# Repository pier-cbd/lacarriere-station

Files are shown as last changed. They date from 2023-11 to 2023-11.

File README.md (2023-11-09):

# Lacarriere Station 

## Specs
### Stage 1
- Powered by a battery recharged by a solar panel
- Three VGA cameras to take 360° photos
- Measures temperature/humidity/pressure with Bosch sensors
- Sends data via 2G+ network
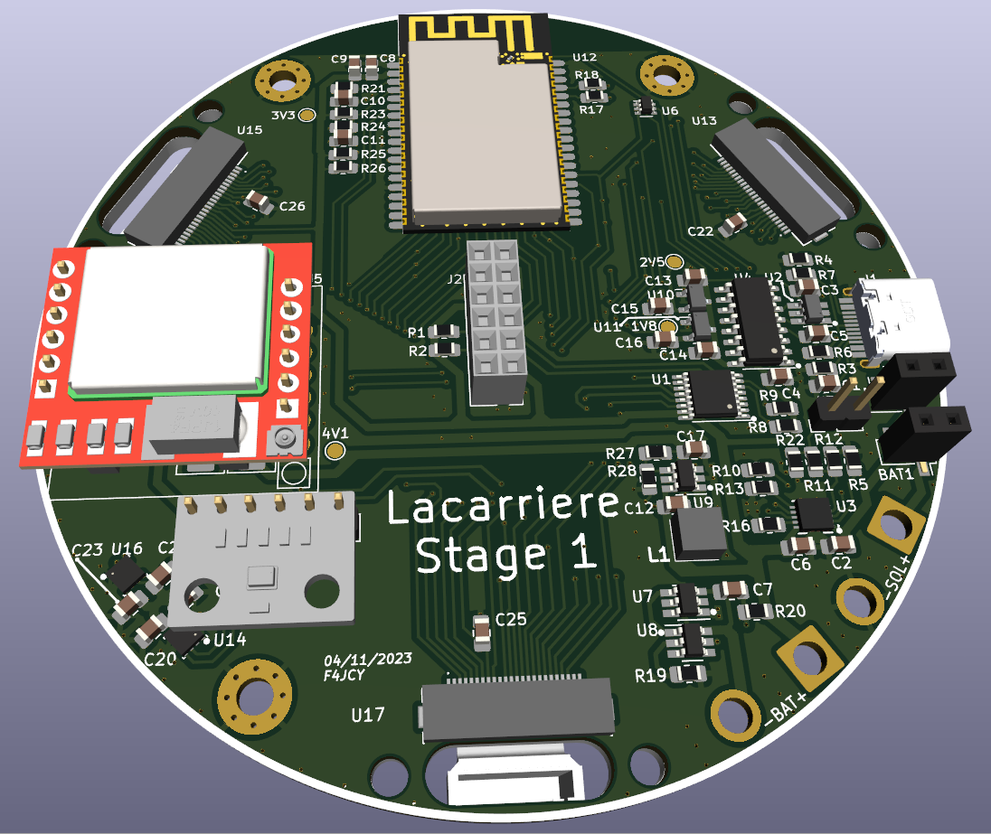
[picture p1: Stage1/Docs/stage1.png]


### Stage 2
...

### Stage 3
...

## Sofwares
- KiCAD 7
- FreeCAD 0.20

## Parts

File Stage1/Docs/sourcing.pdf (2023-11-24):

3 Proto Budget : | 211,968 € | | Mouser Order Aliexpress Order
Price | VAT/Shipping | Already in stock
Mouser Order | 79,88 | 15,98 | Not a component
Aliexpress Order | 16,81 | 6,25
JLCPCB Manufacturing | 2 | 15
Review | 40
Quantity | Designator | Footprint | Designation | STOCK

ORDER
quantity

Mouser
Order

Aliexpress
Order
REF | Price(HT) | Minimum | Manufacturer | REF | Price (€) | Min | Manufacturer | Price (€) | shipping | Minimum
2V8,1V3,3V3,4V1 | TestPoint_Pad_D1.5mmTestPoint
11 | C21,C17,C23,C7,C8,C1,C3,C20,C5,C24,C4 C_0805_2012Metric_Pad1.18x1.45mm_HandSolder 0.1u | 581-KGM21NR71E104KT | 0,093 | 1 | sss | C1711 | 0,0056 | 100 | Samsung Electro-Mechanics | 0 | 35 | 1,05
2 | C18, (C19) | CP_EIA-7343-31_Kemet-D_Pad2.25x2.55mm_HandSolder 100u | 80-T491D107K016 | 0,921 | 1 | KEMET | C110548 | 0,5201 | 1 | KEMET | 0 | 5 | 4,605
3 | C22,C25,C26 | C_0805_2012Metric_Pad1.18x1.45mm_HandSolder 15p | 581-08053A150KAT2A | 0,167 | 1 | KYOCERA AVX | C1794 | 0,0121 | 50 | Samsung Electro-Mechanics | 0 | 15 | 1,91
9 | C2,C16,C13,C10,C12,C15,C14,C6,(C11) C_0805_2012Metric_Pad1.18x1.45mm_HandSolder 1u | 581-KAF21KR71H105KU | 0,288 | 1 | KYOCERA AVX | C28323 | 0,0083 | 50 | Samsung Electro-Mechanics | 44
1 | C9 | C_0805_2012Metric_Pad1.18x1.45mm_HandSolder 10u | 581-0805YC106KAT2A | 0,846 | 1 | KYOCERA AVX | C15850 | 0,0101 | 50 | Samsung Electro-Mechanics | 0 | 10 | 7,47
CON-BAT+ | SolderWire-2.5sqmm_1x02_P8.8mm_D2.4mm_OD4.4mm LiFePo4
CON-SOL+ | SolderWire-2.5sqmm_1x02_P8.8mm_D2.4mm_OD4.4mm Solar_Cell
1 | J1 | USB_C_Receptacle_HRO_TYPE-C-31-M-12 USB_C_USB2.0 | 640-USB4105-GF-A-120 | 0,772 | 1 | GCT | C167321 | 0,3374 | 5 | Jing Extension of the Elec Co. | 0 | 5 | 3,86
1 | J2 | CENTRAL-HEADER Conn_02x06 | 0,398 | 3,52 | 10 | 0 | 20 | 11,48
2 | J4 | PinHeader_1x06_P2.54mm_Vertical (BME KIT) Conn_01x06_Pin | 4,44 | 1 | 2
2 | JUMPER-BAT1, JUMPER-USB1 PinSocket_1x02_P2.54mm_Vertical_SMD_Pin1Right Jumper_2_Bridged | C917636 | 0,0387 | 10 | XKB Connectivity | 15
1 | L1 | XEL4030-222MEC | 2.2u | 994-XEL4030-222MEC | 2,26 | 1 | Coilcraft | C2998753 | 0,6235 | 1 | Sumida | 0 | 3 | 6,78
R11 | R_0805_2012Metric_Pad1.20x1.40mm_HandSolder NC
1 | R13 | R_0805_2012Metric_Pad1.20x1.40mm_HandSolder 62k | 71-CRCW080562K0FKEA | 0,093 | 1 | Vishay / Dale | C17783 | 0,0017 | 100 | UNI-ROYAL(Uniroyal Elec) | 0 | 10 | 0,23
3 | R18,R17,R20 | R_0805_2012Metric_Pad1.20x1.40mm_HandSolder 100R | 71-CRCW0805-100-E3 | 0,093 | 1 | Vishay / Dale | C17408 | 0,0018 | 100 | UNI-ROYAL(Uniroyal Elec) | 0 | 20 | 0,62
1 | R19 | R_0805_2012Metric_Pad1.20x1.40mm_HandSolder 2k | 71-CRCW08052K00JNEA | 0,093 | 1 | Vishay / Dale | C17804 | 0,0018 | 100 | UNI-ROYAL(Uniroyal Elec) | 0 | 10 | 0,19
1 | R5 | R_0805_2012Metric_Pad1.20x1.40mm_HandSolder 375R(0,8A) 750R(0.4A) | 71-CRCW0805-750-E3 | 0,093 | 1 | Vishay / Dale | C17818 | 0,0017 | 100 | UNI-ROYAL(Uniroyal Elec) | 0 | 10 | 0,23
6 | R25,R2,R21,R1,R22,R26 | R_0805_2012Metric_Pad1.20x1.40mm_HandSolder 10k | 71-CRCW080510K0FKEAC | 0,093 | 1 | Vishay / Dale | C17417 | 0,0014 | 100 | UNI-ROYAL(Uniroyal Elec) | 99
1 | R28 | R_0805_2012Metric_Pad1.20x1.40mm_HandSolder 14k | 71-CRCW0805-14K-E3 | 0,093 | 1 | Vishay / Dale | C17467 | 0,0017 | 100 | UNI-ROYAL(Uniroyal Elec) | 0 | 10 | 0,23
2 | R24,R23 | R_0805_2012Metric_Pad1.20x1.40mm_HandSolder 1M | 71-CRCW08051M00FKEAC | 0,093 | 1 | Vishay / Dale | C17514 | 0,0018 | 100 | UNI-ROYAL(Uniroyal Elec) | 98
2 | R3,R4 | R_0805_2012Metric_Pad1.20x1.40mm_HandSolder 5.1k | 71-CRCW08055K10JNEA | 0,093 | 1 | Vishay / Dale | C27834 | 0,0018 | 100 | UNI-ROYAL(Uniroyal Elec) | 0 | 20 | 0,46
4 | R9,R16,R27,R8 | R_0805_2012Metric_Pad1.20x1.40mm_HandSolder 100k | 71-CRCW0805100KFKEBC | 0,093 | 1 | Vishay / Dale | C149504 | 0,0018 | 100 | UNI-ROYAL(Uniroyal Elec) | 0 | 20 | 0,58
6 | R10,R7,R15,R6,R14,R11 | R_0805_2012Metric_Pad1.20x1.40mm_HandSolder 0R | 71-CRCW08050000Z0EC | 0,093 | 1 | Vishay / Dale | C17477 | 0,0016 | 100 | UNI-ROYAL(Uniroyal Elec) | 0 | 20 | 0,46
TH1 | PinHeader_1x02_P2.54mm_Vertical NTC
1 | U1 | TSSOP-16_4.4x5mm_P0.65mm PCA9557PW | 595-PCA9557PWR | 1,4 | 1 | Texas Instruments | C141380 | 0,43 | 1 | NXP Semicon | 0 | 3 | 4,2
1 | U10 | SOT-23-3 | XC6206P182MR-G | 865-XC6206P182MR-G | 0,651 | 1 | Torex Semiconductor | C424700 | 0,1349 | 5 | Torex Semiconductor | 0 | 5 | 3,255
1 | U11 | SOT-23-3 | XC6206P252MR-G | 865-XC6206P252MR-G | 0,577 | 1 | Torex Semiconductor | C5250983 | 0,0168 | 20 | TWGMC | 0
1 | U12 | ESP32-WROVER | ESP32_WROVER | 356-ESP32WRVIE2864UC | 3,15 | 1 | Espressif Systems | C529591 | 3,9246 | 1 | Espressif Systems | 0 | 3 | 9,45
3 | U15,U13,U17 | F34G1A7Q1E8C24 ~ | 649-F34G1A7Q1E8C24 | 0,437 | 1 | Amphenol Aorora | C5373439 | 0,0636 | 5 | SHOU HAN | 0 | 10 | 3,71
2 | U14,U16 | Bosch_LGA-8_2.5x2.5mm_P0.65mm_ClockwisePinNumbering BME280 | 262-BME280 | 5,9 | 1 | Bosch Sensortec | C92489 | 3,4781 | 1 | Bosch Sensortec | 0 | 4 | 23,6
1 | U2 | SOT-23-6_Handsoldering USBLC6-2SC6 | 511-USBLC6-2SC6 | 0,567 | 1 | STMicroelectronics
1 | U3 | VSON10_BQ25171_3X3_TEX-M BQ25171QWDRCRQ1 | 595-BQ25171QWDRCRQ1 | 1,71 | 1 | Texas Instruments | C2861221 | 1,3995 | 1 | Texas Instruments | 12
1 | U4 | SOIC-16_3.9x9.9mm_P1.27mm CH340C | C84681 | 0,4433 | 1 | WCH(Jiangsu Qin Heng) | 0,468 | 0,56 | 10 | 0 | 10 | 5,24
1 | U6 | SOT-363_SC-70-6 | UMH3N | 755-UMH3NTN | 0,428 | 1 | ROHM Semiconductor | C62892 | 0,0502 | 10 | Jiangsu Changjing | 0 | 5 | 2,14
1 | U5 | SIM800L-CORE | SIM800L-CORE | 2,77 | 1 | 2
1 | U7 | SOT-23-6_Handsoldering FS8205 | C32254 | 0,169 | 5 | Fortune Semicon | 0,098 | 0,84 | 10 | 0 | 10 | 1,82
1 | U8 | SOT-23-6_Handsoldering HY2112 (HB) | C168763 | 0,1222 | 5 | HYCON Tech | 0,319 | 1,33 | 10 | 0 | 10 | 4,52
1 | U9 | SOT-23-6_Handsoldering TLV61070A | 595-TLV61070ADBVR | 0,465 | 1 | Texas Instruments | C6881375 | 0,2857 | 5 | Texas Instruments | 0 | 5 | 2,325
77,355 | 23,06
Mouser | LCSC | Aliexpress

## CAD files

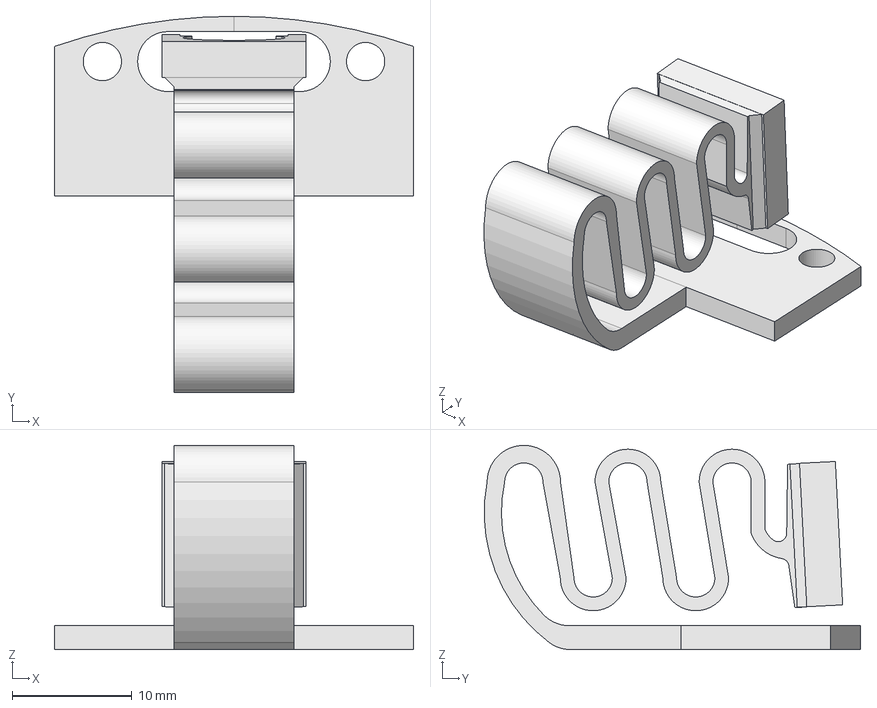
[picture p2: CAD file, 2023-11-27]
Stage1/Kicad/3D/CAMERA_HOLDER_V7.step
30.0 x 31.4 x 17.1 mm

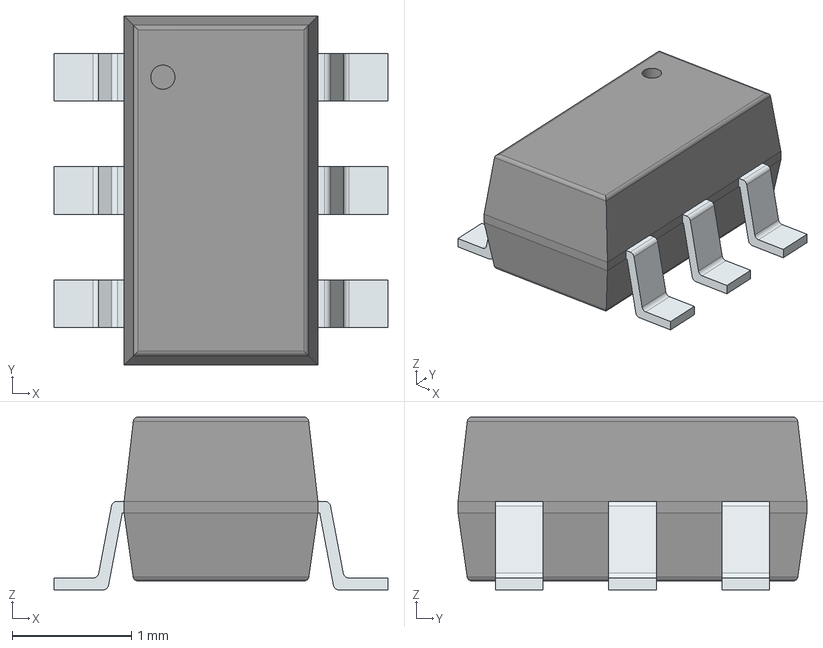
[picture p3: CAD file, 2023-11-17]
Stage1/Kicad/3D/USBLC6-2SC6.stp
2.80 x 2.92 x 1.45 mm
PinsArrayLR

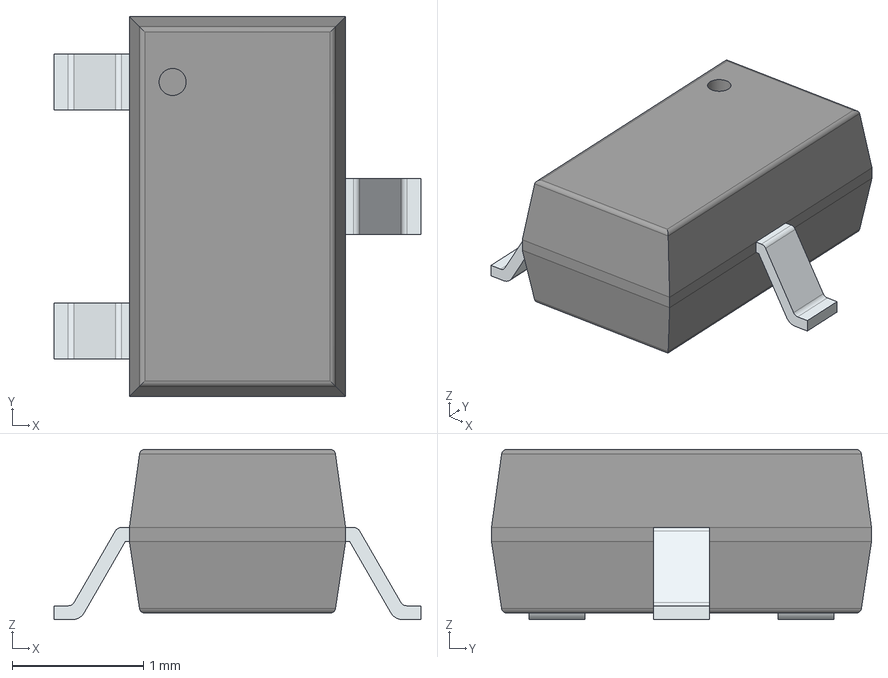
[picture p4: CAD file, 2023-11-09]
Stage1/Kicad/3D/XC6206P282MR-G.stp
2.80 x 2.90 x 1.30 mm
PinsArrayL
FilletPinR

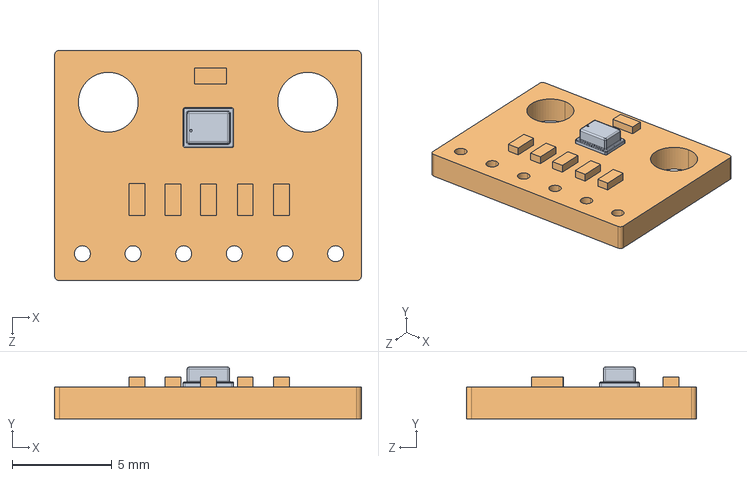
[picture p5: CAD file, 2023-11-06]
Stage1/Kicad/3D/BME280_SENSOR_MODULE.STEP
15.4 x 2.60 x 11.6 mm

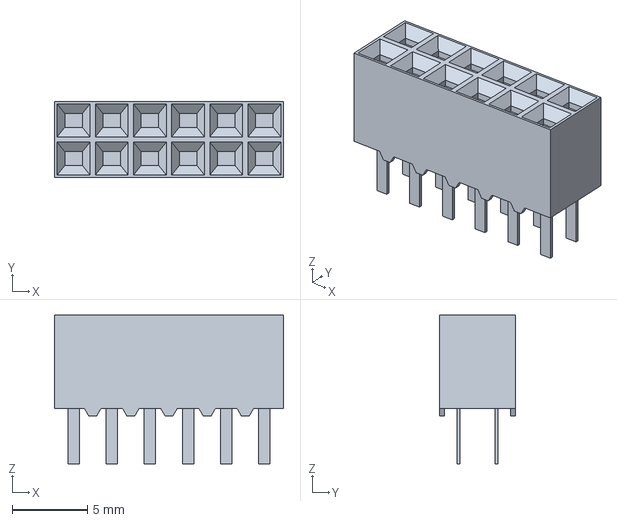
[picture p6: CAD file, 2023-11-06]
Stage1/Kicad/3D/CENTRAL_HEADER_02x06.stp
15.2 x 5.03 x 9.91 mm

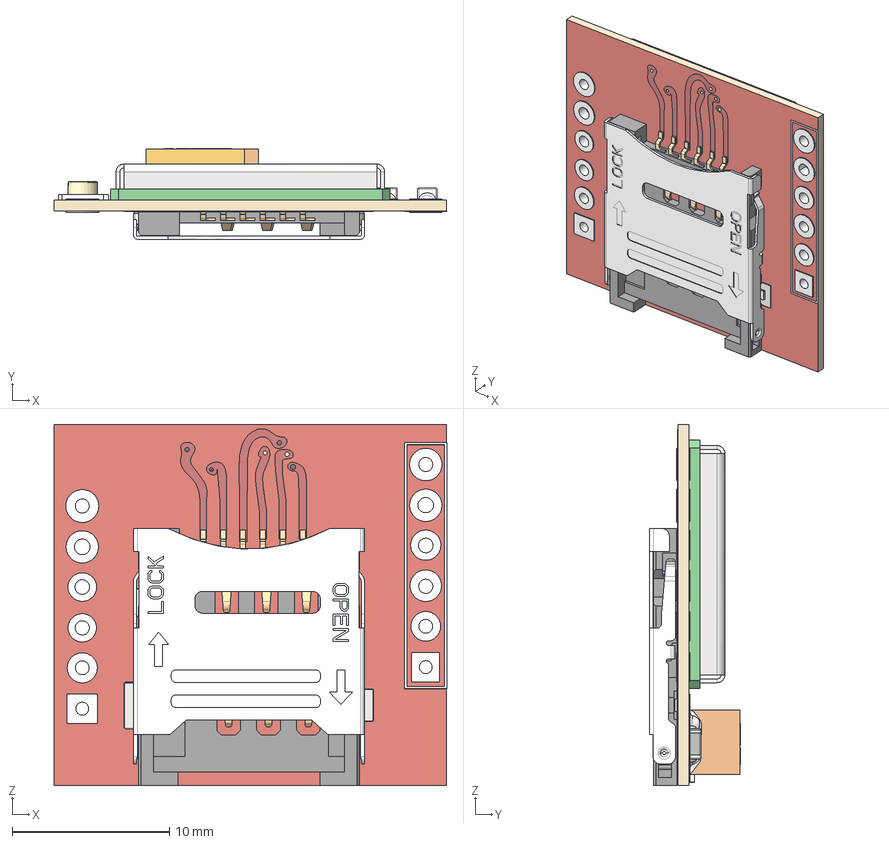
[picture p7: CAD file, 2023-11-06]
Stage1/Kicad/3D/SIM800L.step
25.0 x 5.77 x 23.0 mm
PCB
Cage
CH03-HB

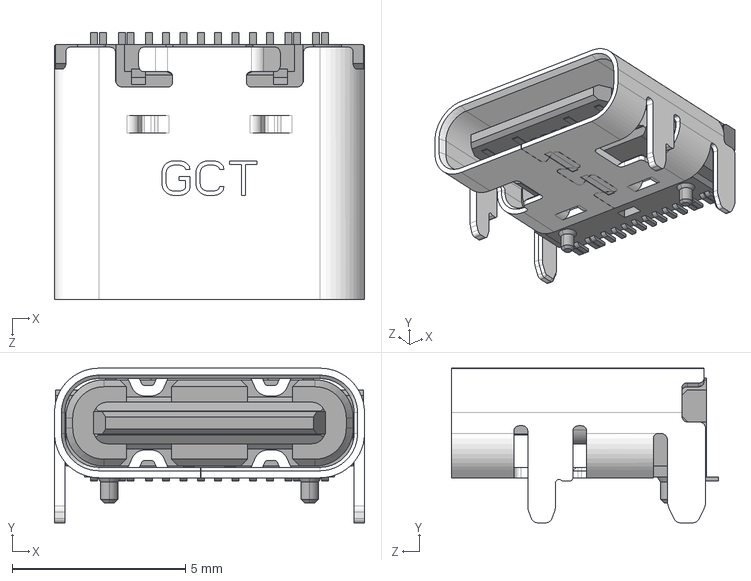
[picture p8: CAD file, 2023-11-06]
Stage1/Kicad/3D/USB-C_2-0_CONNECTOR.stp
8.94 x 4.46 x 7.70 mm
USB4105-15-A-120_PART2^USB4105-15-A-120(2)_USB4105-15-A-120
USB4105-15-A-120_PART1^USB4105-15-A-120(2)_USB4105-15-A-120

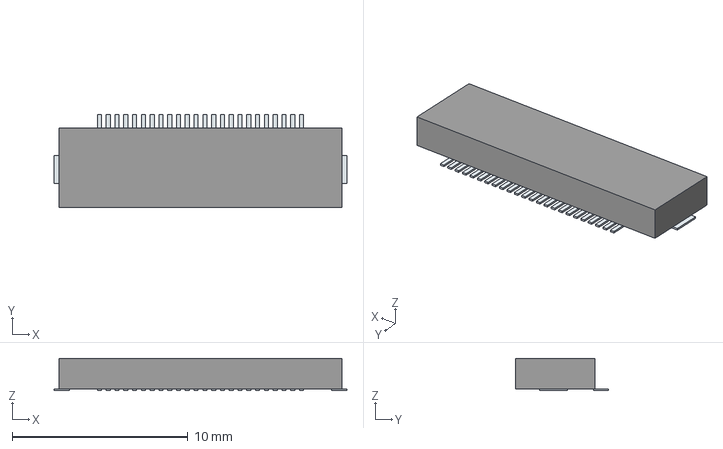
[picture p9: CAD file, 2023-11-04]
Stage1/Kicad/3D/FFC_FPC_24PIN_CLAMSHELL.stp
16.7 x 5.27 x 1.85 mm
Pins

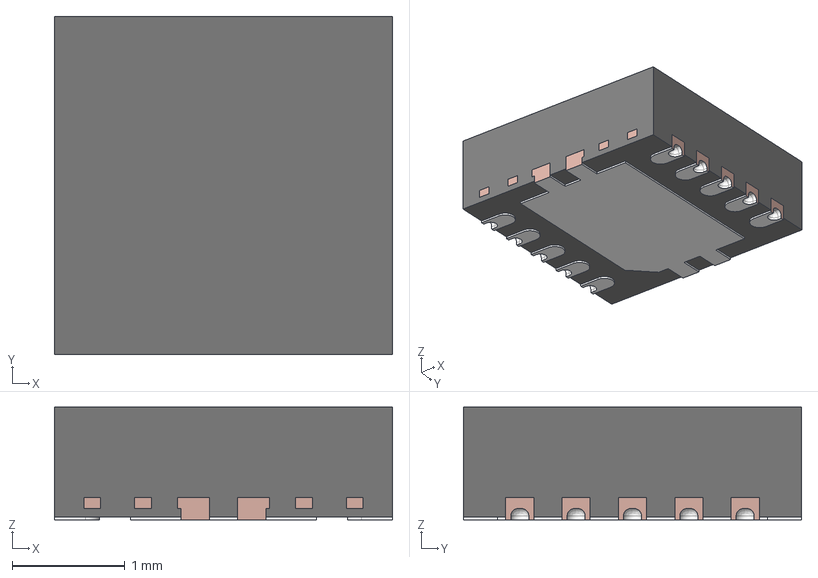
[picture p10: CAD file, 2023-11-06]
Stage1/Kicad/3D/BQ25171QWDRCRQ1.stp
3.00 x 3.00 x 1.00 mm
BODY-SON
FRAME-DRC0010U

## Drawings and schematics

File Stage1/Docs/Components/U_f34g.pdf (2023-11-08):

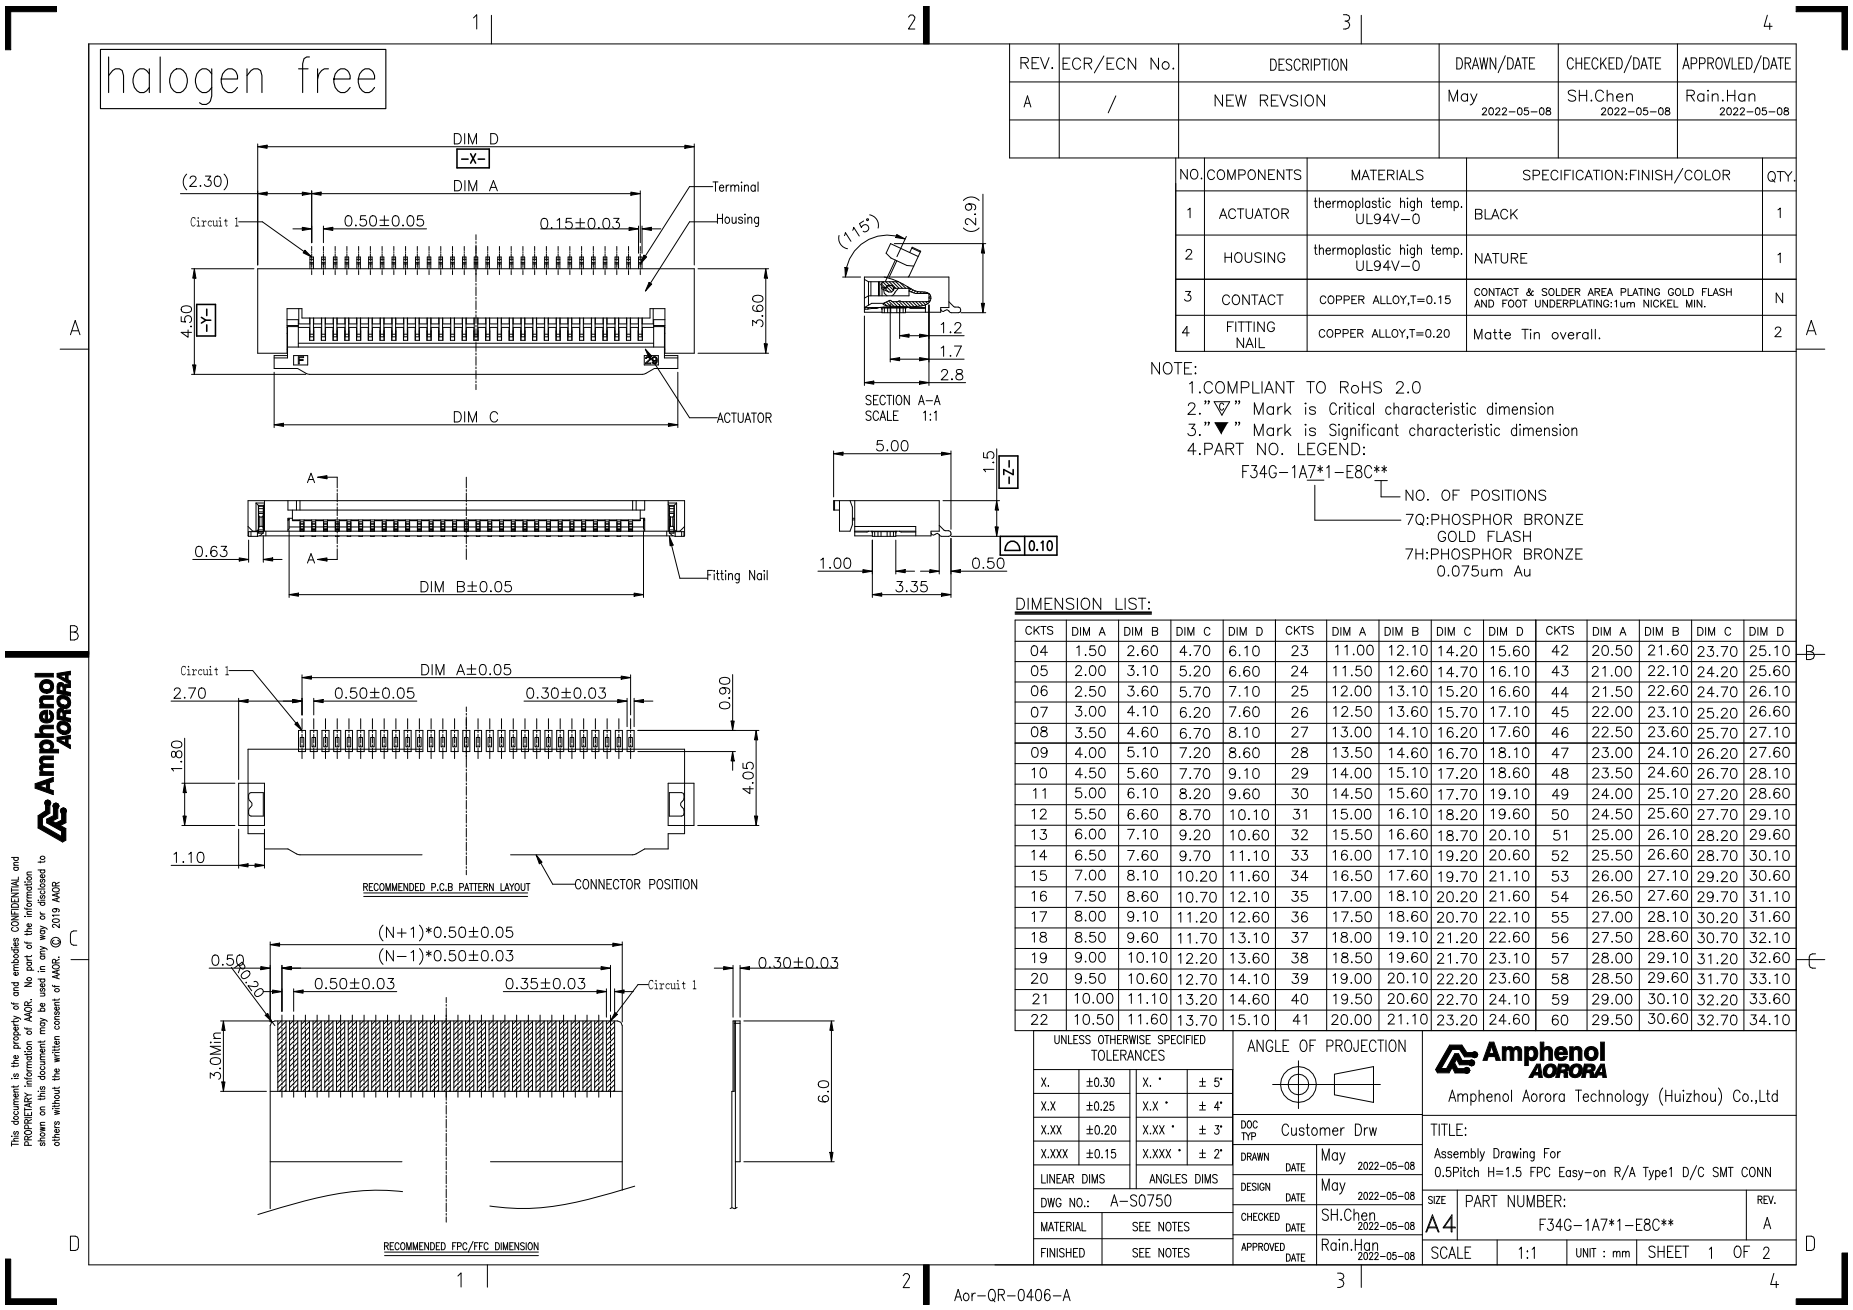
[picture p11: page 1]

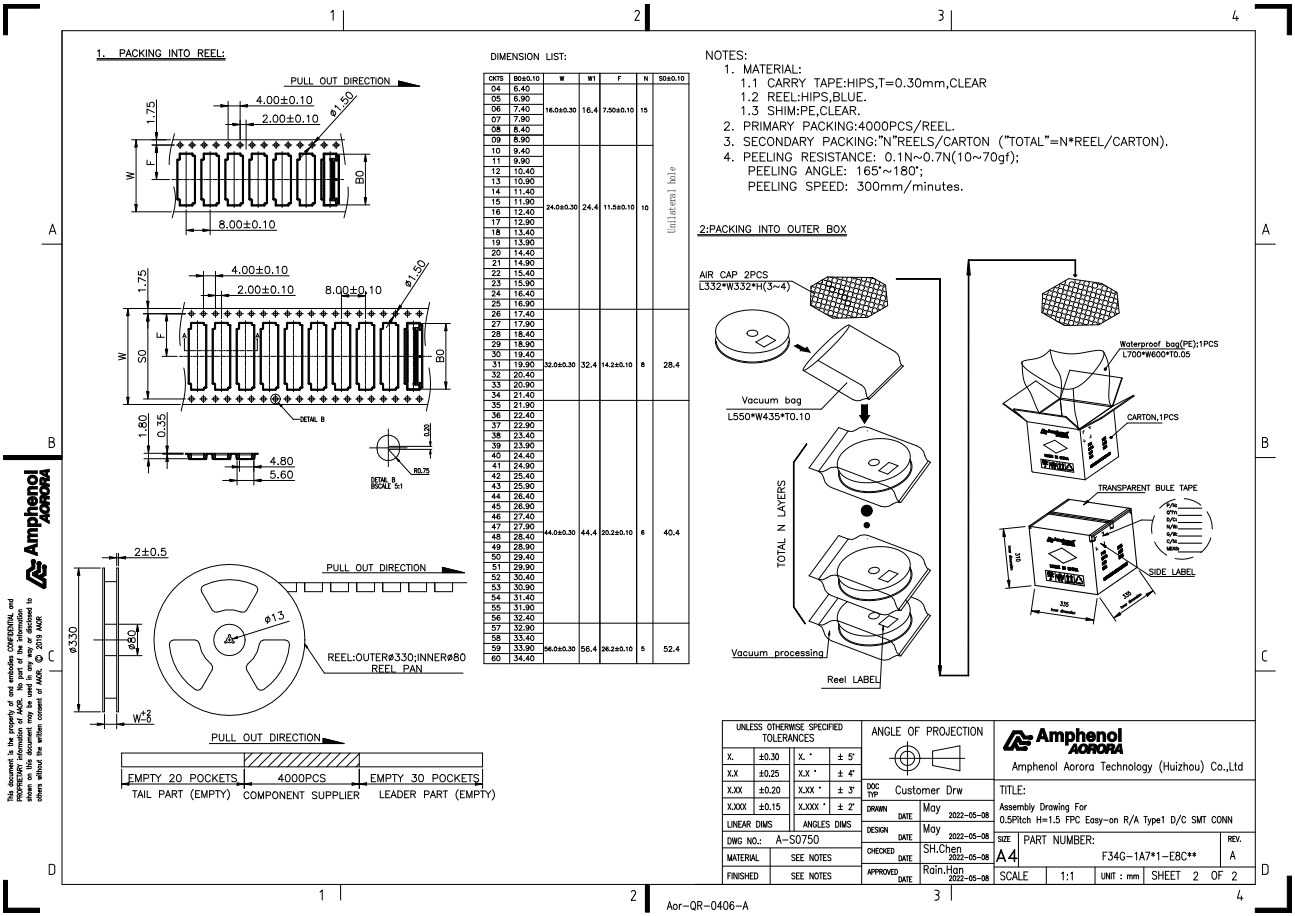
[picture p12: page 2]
Unilateral hole

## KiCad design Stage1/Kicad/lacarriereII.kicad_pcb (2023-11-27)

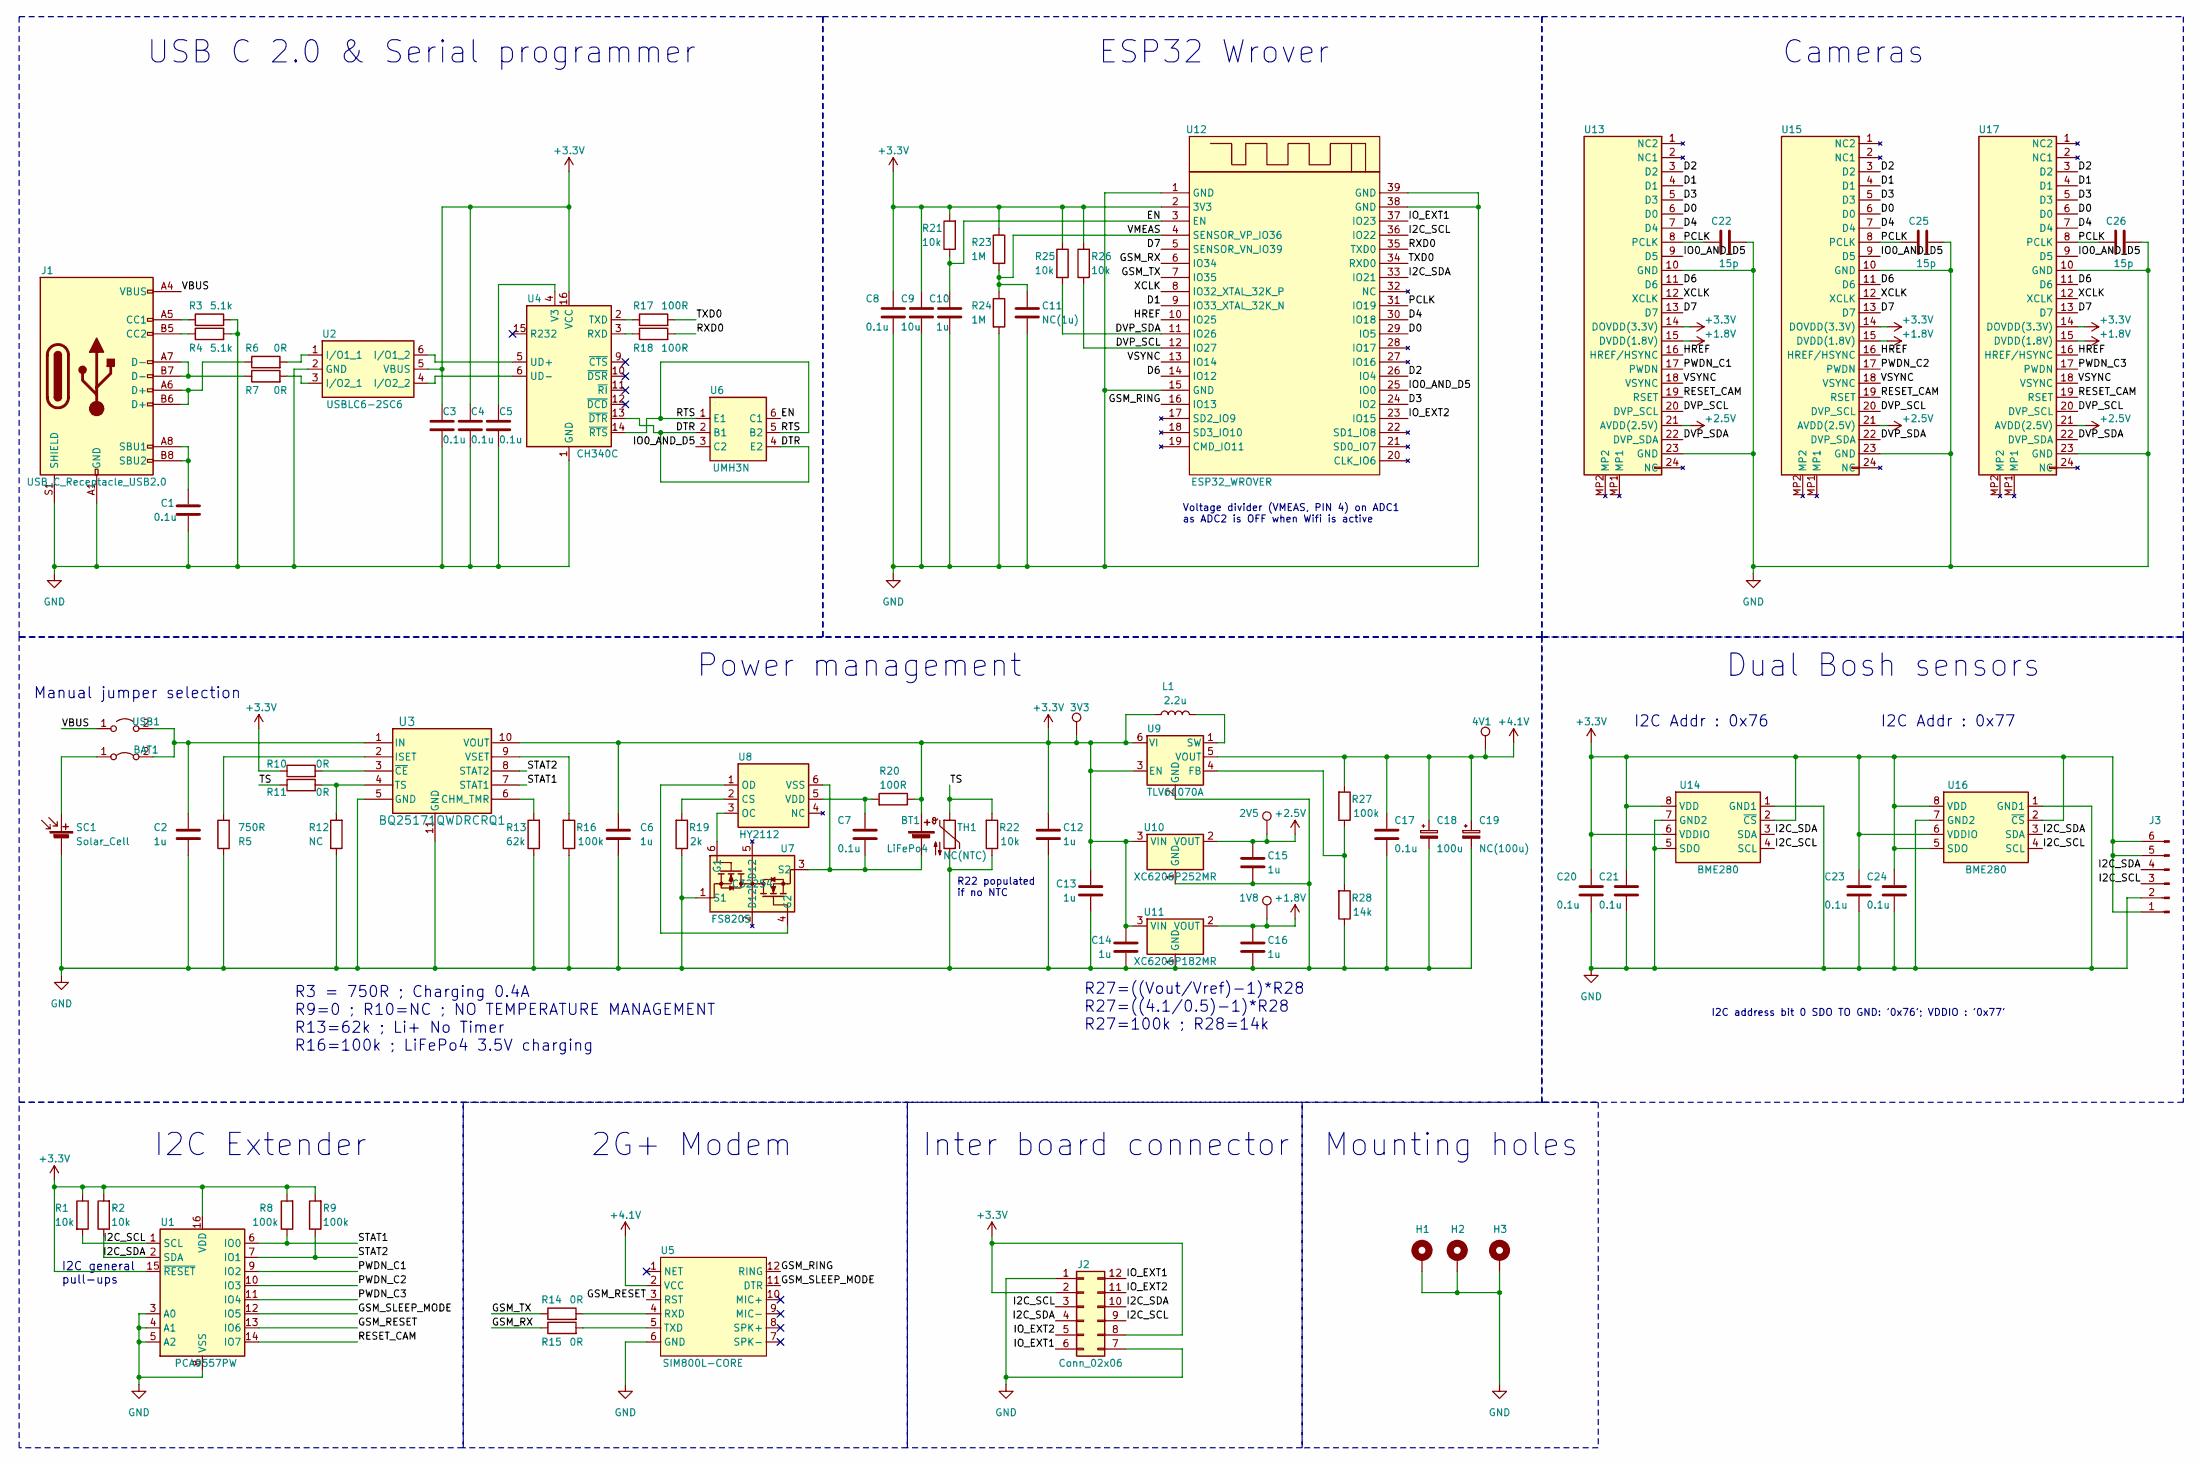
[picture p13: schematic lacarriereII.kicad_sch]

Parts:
1V8, 2V5, 3V3, 4V1: TestPoint; TestPoint_Pad_D1.5mm
BAT1: Jumper_2_Bridged; PinSocket_1x02_P2.54mm_Vertical_SMD_Pin1Right
BT1: LiFePo4; SolderWire-2.5sqmm_1x02_P8.8mm_D2.4mm_OD4.4mm
C1, C3, C4, C5, C7, C8, C17, C20, C21, C23, C24: 0.1u; C_0805_2012Metric_Pad1.18x1.45mm_HandSolder; LCSC C1711
C2, C6, C10, C12, C13, C14, C15, C16: 1u; C_0805_2012Metric_Pad1.18x1.45mm_HandSolder; LCSC C28323
C9: 10u; C_0805_2012Metric_Pad1.18x1.45mm_HandSolder; LCSC C15850
C11: NC(1u); C_0805_2012Metric_Pad1.18x1.45mm_HandSolder; LCSC C28323
C18: 100u; CP_EIA-7343-31_Kemet-D_Pad2.25x2.55mm_HandSolder; LCSC C110548
C19: NC(100u); CP_EIA-7343-31_Kemet-D_Pad2.25x2.55mm_HandSolder; LCSC C110548
C22, C25, C26: 15p; C_0805_2012Metric_Pad1.18x1.45mm_HandSolder; LCSC C1794
H1, H2, H3: MountingHole_Pad; MountingHole_3.2mm_M3_Pad_Via
J1: USB_C_Receptacle_USB2.0; USB_C_Receptacle_HRO_TYPE-C-31-M-12
J2: Conn_02x06; CENTRAL-HEADER
J3: Conn_01x06_Pin; PinHeader_1x06_P2.54mm_Vertical
L1: 2.2u; XEL4030222MEC
R1, R2, R21, R22, R25, R26: 10k; R_0805_2012Metric_Pad1.20x1.40mm_HandSolder
R3, R4: 5.1k; R_0805_2012Metric_Pad1.20x1.40mm_HandSolder
R5: 750R; R_0805_2012Metric_Pad1.20x1.40mm_HandSolder
R6, R7, R10, R11, R14, R15: 0R; R_0805_2012Metric_Pad1.20x1.40mm_HandSolder
R8, R9, R16, R27: 100k; R_0805_2012Metric_Pad1.20x1.40mm_HandSolder
R12: NC; R_0805_2012Metric_Pad1.20x1.40mm_HandSolder
R13: 62k; R_0805_2012Metric_Pad1.20x1.40mm_HandSolder
R17, R18, R20: 100R; R_0805_2012Metric_Pad1.20x1.40mm_HandSolder
R19: 2k; R_0805_2012Metric_Pad1.20x1.40mm_HandSolder
R23, R24: 1M; R_0805_2012Metric_Pad1.20x1.40mm_HandSolder
R28: 14k; R_0805_2012Metric_Pad1.20x1.40mm_HandSolder; LCSC C17464
SC1: Solar_Cell; SolderWire-2.5sqmm_1x02_P8.8mm_D2.4mm_OD4.4mm
TH1: NC(NTC); PinHeader_1x02_P2.54mm_Vertical
U1: PCA9557PW; TSSOP-16_4.4x5mm_P0.65mm
U2: USBLC6-2SC6; SOT-23-6_Handsoldering; Mouser Part Number 511-USBLC6-2SC6
U3: BQ25171QWDRCRQ1; VSON10_BQ25171_3X3_TEX-M
U4: CH340C; SOIC-16_3.9x9.9mm_P1.27mm
U5: SIM800L-CORE
U6: UMH3N; SOT-363_SC-70-6; LCSC C123008
U7: FS8205; SOT-23-6_Handsoldering; LCSC C32254
U8: HY2112; SOT-23-6_Handsoldering; LCSC C168763
U9: TLV61070A; SOT-23-6_Handsoldering; LCSC C6881375
U10: XC6206P252MR; SOT-23-3; LCSC C2934870
U11: XC6206P182MR; SOT-23-3; LCSC C424700
U12: ESP32_WROVER; ESP32-WROVER
U13, U15, U17: F34G1A7Q1E8C24
U14, U16: BME280; Bosch_LGA-8_2.5x2.5mm_P0.65mm_ClockwisePinNumbering
USB1: Jumper_2_Open; PinSocket_1x02_P2.54mm_Vertical_SMD_Pin1Right

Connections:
+1V2: 1V8.1, C16.1, U11.2 (VOUT), U13.15 (DVDD(1.8V)), U15.15 (DVDD(1.8V)), U17.15 (DVDD(1.8V))
+2V8: 2V5.1, C15.1, U10.2 (VOUT), U13.21 (AVDD(2.5V)), U15.21 (AVDD(2.5V)), U17.21 (AVDD(2.5V))
+3.3V: 3V3.1, BT1.1 (+), C3.1, C4.1, C6.1, C8.1, C9.1, C12.1, C13.1, C14.1, C20.1, C21.1, C23.1, C24.1, J2.2, J2.8, J3.1, J3.5, J3.6, L1.1, R1.1, R2.2, R8.2, R9.2, R10.1, R20.1, R21.2, R23.1, R25.1, R26.2, U1.15 (~RESET), U1.16 (VDD), U2.5 (VBUS), U3.10 (VOUT), U4.16 (VCC), U9.3 (EN), U9.6 (VI), U10.3 (VIN), U11.3 (VIN), U12.2 (3V3), U13.14 (DOVDD(3.3V)), U14.2 (~CS), U14.6 (VDDIO), U14.8 (VDD), U15.14 (DOVDD(3.3V)), U16.2 (~CS), U16.5 (SDO), U16.6 (VDDIO), U16.8 (VDD), U17.14 (DOVDD(3.3V)); also elsewhere on the board
+4V: 4V1.1, C17.1, C18.1, C19.1, R27.2, U5.2 (VCC), U9.5 (VOUT)
/D0: U12.29 (IO5), U13.6 (D0), U15.6 (D0), U17.6 (D0)
/D1: U12.9 (IO33_XTAL_32K_N), U13.4 (D1), U15.4 (D1), U17.4 (D1)
/D2: U12.26 (IO4), U13.3 (D2), U15.3 (D2), U17.3 (D2)
/D3: U12.24 (IO2), U13.5 (D3), U15.5 (D3), U17.5 (D3)
/D4: U12.30 (IO18), U13.7 (D4), U15.7 (D4), U17.7 (D4)
/D6: U12.14 (IO12), U13.11 (D6), U15.11 (D6), U17.11 (D6)
/D7: U12.5 (SENSOR_VN_IO39), U13.13 (D7), U15.13 (D7), U17.13 (D7)
/DTR: U4.13 (~DTR), U6.2 (B1), U6.4 (E2)
/DVP_SCL: R26.1, U12.12 (IO27), U13.20 (DVP_SCL), U15.20 (DVP_SCL), U17.20 (DVP_SCL)
/DVP_SDA: R25.2, U12.11 (IO26), U13.22 (DVP_SDA), U15.22 (DVP_SDA), U17.22 (DVP_SDA)
/EN: C10.1, R21.1, U6.6 (C1), U12.3 (EN)
/GSM_RESET: U1.13 (IO6), U5.3 (RST)
/GSM_RING: U5.12 (RING), U12.16 (IO13)
/GSM_RX: R15.1, U12.6 (IO34)
/GSM_SLEEP_MODE: U1.12 (IO5), U5.11 (DTR)
/GSM_TX: R14.1, U12.7 (IO35)
/HREF: U12.10 (IO25), U13.16 (HREF/HSYNC), U15.16 (HREF/HSYNC), U17.16 (HREF/HSYNC)
/I2C_SCL: J2.3, J2.9, J3.3, R1.2, U1.1 (SCL), U12.36 (IO22), U14.4 (SCL), U16.4 (SCL)
/I2C_SDA: J2.4, J2.10, J3.4, R2.1, U1.2 (SDA), U12.33 (IO21), U14.3 (SDA), U16.3 (SDA)
/IO0_AND_D5: U6.3 (C2), U12.25 (IO0), U13.9 (D5), U15.9 (D5), U17.9 (D5)
/IO_EXT1: J2.6, J2.12, U12.37 (IO23)
/IO_EXT2: J2.5, J2.11, U12.23 (IO15)
/PCLK: C22.1, C25.1, C26.1, U12.31 (IO19), U13.8 (PCLK), U15.8 (PCLK), U17.8 (PCLK)
/PWDN_C1: U1.9 (IO2), U13.17 (PWDN)
/PWDN_C2: U1.10 (IO3), U15.17 (PWDN)
/PWDN_C3: U1.11 (IO4), U17.17 (PWDN)
/RESET_CAM: U1.14 (IO7), U13.19 (RSET), U15.19 (RSET), U17.19 (RSET)
/RTS: U4.14 (~RTS), U6.1 (E1), U6.5 (B2)
/RXD0: R18.2, U12.35 (TXD0)
/STAT1: R8.1, U1.6 (IO0), U3.7 (STAT1)
/STAT2: R9.1, U1.7 (IO1), U3.8 (STAT2)
/TS: R11.1, R22.2, TH1.1
/TXD0: R17.2, U12.34 (RXD0)
/VBUS: J1.A4 (VBUS), J1.A9 (VBUS), J1.B4 (VBUS), J1.B9 (VBUS), USB1.1 (A)
/VMEAS: C11.1, R23.2, R24.1, U12.4 (SENSOR_VP_IO36)
/VSYNC: U12.13 (IO14), U13.18 (VSYNC), U15.18 (VSYNC), U17.18 (VSYNC)
/XCLK: U12.8 (IO32_XTAL_32K_P), U13.12 (XCLK), U15.12 (XCLK), U17.12 (XCLK)
GND: C1.2, C2.2, C3.2, C4.2, C5.2, C6.2, C8.2, C9.2, C10.2, C11.2, C12.2, C13.2, C14.2, C15.2, C16.2, C17.2, C18.2, C19.2, C20.2, C21.2, C22.2, C23.2, C24.2, C25.2, C26.2, H1.1, H2.1, H3.1, J1.A1 (GND), J1.A12 (GND), J1.B1 (GND), J1.B12 (GND), J1.S1 (SHIELD), J2.1, J2.7, J3.2, R3.2, R4.2, R5.1, R12.1, R13.1, R16.1, R19.1, R22.1, R24.2, R28.1, SC1.2 (-), TH1.2, U1.3 (A0), U1.4 (A1), U1.5 (A2), U1.8 (VSS), U2.2 (GND), U3.5 (GND), U3.11 (GND), U4.1 (GND), U5.6 (GND), U7.1 (S1), U9.2 (GND), U10.1 (GND), U11.1 (GND), U12.1 (GND), U12.15 (GND), U12.38 (GND), U12.39 (GND), U13.10 (GND), U13.23 (GND), U14.1 (GND1), U14.5 (SDO), U14.7 (GND2), U15.10 (GND), U15.23 (GND), U16.1 (GND1), U16.7 (GND2), U17.10 (GND), U17.23 (GND); also elsewhere on the board
unnamed 42: BAT1.1 (A), SC1.1 (+); also elsewhere on the board
unnamed: BAT1.2 (B), C2.1, U3.1 (IN), USB1.2 (B)
unnamed 44: BT1.2 (-), C7.2, U7.3 (S2), U8.6 (VSS); also elsewhere on the board
unnamed: J1.A5 (CC1), R3.1
unnamed: J1.B5 (CC2), R4.1
unnamed: J1.A6 (D+), J1.B6 (D+), R6.1
unnamed: J1.A7 (D-), J1.B7 (D-), R7.1
unnamed: C1.1, J1.A8 (SBU1), J1.B8 (SBU2)
unnamed: R6.2, U2.1 (I/O1_1)
unnamed: U2.6 (I/O1_2), U4.5 (UD+)
unnamed: R7.2, U2.3 (I/O2_1)
unnamed: U2.4 (I/O2_2), U4.6 (UD-)
unnamed: R13.2, U3.6 (CHM_TMR)
unnamed: R5.2, U3.2 (ISET)
unnamed: R11.2, R12.2, U3.4 (TS)
unnamed: R16.2, U3.9 (VSET)
unnamed: R10.2, U3.3 (~CE)
unnamed: R18.1, U4.3 (RXD)
unnamed: R17.1, U4.2 (TXD)
unnamed: C5.1, U4.4 (V3)
unnamed: R14.2, U5.4 (RXD)
unnamed: R15.2, U5.5 (TXD)
unnamed: U7.6 (G1), U8.3 (OC)
unnamed: U7.4 (G2), U8.1 (OD)
unnamed: R19.2, U8.2 (CS)
unnamed: C7.1, R20.2, U8.5 (VDD)
unnamed: R27.1, R28.2, U9.4 (FB)
unnamed: L1.2, U9.1 (SW)

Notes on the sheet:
Inter board connector
I2C Extender
I2C address bit 0 SDO TO GND: '0x76'; VDDIO : '0x77'
I2C Addr : 0x76
2G+ Modem
Dual Bosh sensors
R22 populated if no NTC
I2C Addr : 0x77
Manual jumper selection
Mounting holes
I2C general pull-ups
Cameras
R27=((Vout/Vref)-1)*R28 R27=((4.1/0.5)-1)*R28 R27=100k ; R28=14k
R3 = 750R ; Charging 0.4A R9=0 ; R10=NC ; NO TEMPERATURE MANAGEMENT R13=62k ; Li+ No Timer R16=100k ; LiFePo4 3.5V charging
ESP32 Wrover
USB C 2.0 & Serial programmer
Power management
Voltage divider (VMEAS, PIN 4) on ADC1 as ADC2 is OFF when Wifi is active

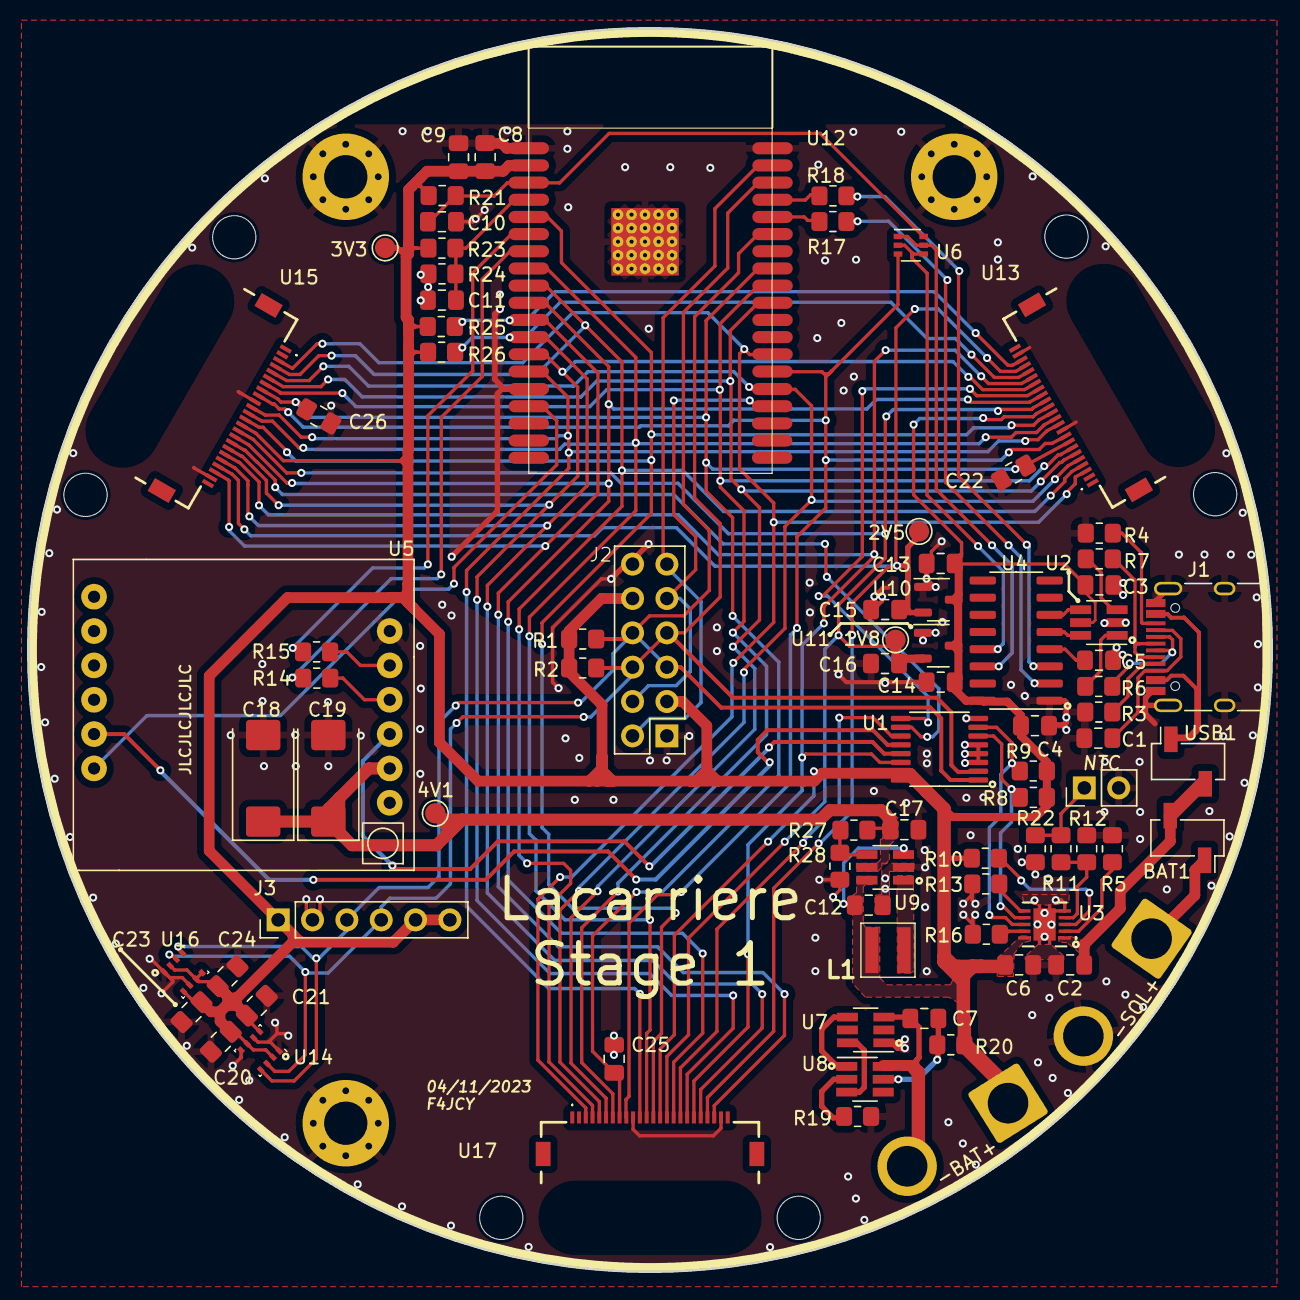
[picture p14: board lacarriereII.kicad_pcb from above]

Board: 2 copper layers, 92.0 x 92.0 mm, 87 parts (0 on the bottom side), 70 nets.

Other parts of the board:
-BAT+: LiFePo4; SolderWire-2.5sqmm_1x02_P8.8mm_D2.4mm_OD4.4mm
-SOL+: Solar_Cell; SolderWire-2.5sqmm_1x02_P8.8mm_D2.4mm_OD4.4mm

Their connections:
+3.3V: -BAT+.1 (+); also elsewhere on the board
GND: -SOL+.2 (-); also elsewhere on the board
unnamed 42: -SOL+.1 (+); also elsewhere on the board
unnamed 44: -BAT+.2 (-); also elsewhere on the board

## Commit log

2023-11-04 [add] Kicad 7 project folder of the v2 board
    [5-534998-6.stp, 74438357022.stp, BME280_SENSOR_MODULE.STEP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]
2023-11-05 [change] ov2640 footprint and add BOM
    [lacarriereII.csv, lacarriereII.kicad_pcb, lacarriereII.kicad_sch]
2023-11-06 [refactor] folder structure
    [5-534998-6.stp, 74438357022.stp, BME280_SENSOR_MODULE.STEP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]
2023-11-07 [add] mounting holes + custom footprints lib
    [lacarriereII.kicad_pcb, lacarriereII.kicad_sch]
2023-11-08 [update] sourcing BOM + add main components datasheets
2023-11-09 [add] white border + stage1 image
    [XC6206P282MR-G.stp, lacarriereII.kicad_pcb, lacarriereII.kicad_sch]
2023-11-09 Update README.md
    [add] stage1 image
2023-11-17 [update] Stage1 schematic after olli's review
    [USBLC6-2SC6.stp, lacarriereII.kicad_pcb, lacarriereII.kicad_sch]
2023-11-17 [fix] a few mistakes on schematic ... ready to reroute!
    [lacarriereII.kicad_pcb, lacarriereII.kicad_sch]
2023-11-24 [reroute] pcb board after oli's review
    [lacarriereII.kicad_pcb, lacarriereII.kicad_sch]
2023-11-24 [update] sourcing file + minors component placements on pcb
    [lacarriereII.kicad_pcb]
2023-11-24 [change] via size to be compatible witch jlc capabilities specs
    [lacarriereII.kicad_pcb, lacarriereII.kicad_sch]
2023-11-27 [update] camera holder and Stage1 picture
    [CAMERA_HOLDER_V6.step, CAMERA_HOLDER_V7.step, lacarriereII.kicad_pcb]
